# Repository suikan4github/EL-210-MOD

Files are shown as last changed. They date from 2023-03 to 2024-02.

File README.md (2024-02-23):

# EL-210-MOD
Alternative circuit for SHARP EL-210/EL-215 calculator

# Description

This is a circuit/board design for the alternate PCB for the SHARP EL-210/215 calculators. SHARP EL-210 series are manufactured around early 1980th. 
By using this alternate PCB, you can program any program as firmware of this
classic VFD calculator. 

There is an dedicated RPN firmware is located in the [rpn2026](https://github.com/suikan4github/rpn2026) project.

To make your own RPN calculator,
user must follow the procedure : 
1. Take the main board of the EL-210 out. 
1. Move the VFD from the old board to this board. 
1. Set this board into the EL-210 calculator. 
1. Program the board with the appropriate RPN firmware. 

# Circuit Design

You can found additional design resources : 
- [Schematic diagram](doc/EL-210-MOD.pdf).
- [Parts list](doc/partslist.csv).

## VFD specification
The VFD is 9-ST-20, manufactured by Futaba. The specification is not disclosed. 
Pin assignment has been investigated by [LI2026ODP](https://github.com/suikan4github/LI2026ODP/wiki/LI2026A) project.
- Anode voltage : 25V
- Heater voltage : 2.5v (Differential square wave drive), 21mA. 
- Grid cutoff : 4V

## Heater driver
The heater must be driven by differential alternate current. This is required to make the flat brightness between right-end and left-end of the VFD. If you drive 
the heater by DC, the voltage slope of the heater will make the slop of the brightness.

The analog switch provide the low voltage drop out current switching. The timing
is made by MCU timer.

## Grid bias 
The grid bias is required 4. Because the balanced drive of the heater makes
1.65V grid bias, we need only 2.5V more. 

## Key matrix
The key matrix has been investigated by also [LI2026ODP](https://github.com/suikan4github/LI2026ODP/wiki/KeyMatrix) project. 

The EL-21x series key matrix doesn't have any protection diode. Thus, to prevent the signal shortage,
the GPIO pins for the key matrix have to be configured : 
- Row : Open Drain output.
- Col : Input with pull-up register. 

To check the button pushed, output the "L" from the Row.
If the Column get "L", the button is pushed. 

|  Row  | Column 0  |  Column 1  |  Column 2  |
| :---: | :---: | :---: | :---: |
| 0 | CE |  X->M | 0 |
| 1 | | 7 | 4 |
| 2 | CM | 8 | 1 |
| 3 | . | 5 | % |
| 4 | + | RM | 2 |
| 5 | C | 9 | = |
| 6 | / | M- | |
| 7 | * | 6 | 3 |
| 8 | - | M+ |  sqrt |

## 24V
To supply the 24V to VFD, set EN24 signal to "H".

# Caution
In the case you order the PCB to a board manufacturer, you must specify the 
PCB thinness as 1.0mm. The standard 1.3mm is too thick. 

# Known Problems
The Grid bias is not deep as expected. It is -0.9V while expected -2.5v. 
It is left untouched because it is not problematic. 

# Gallery
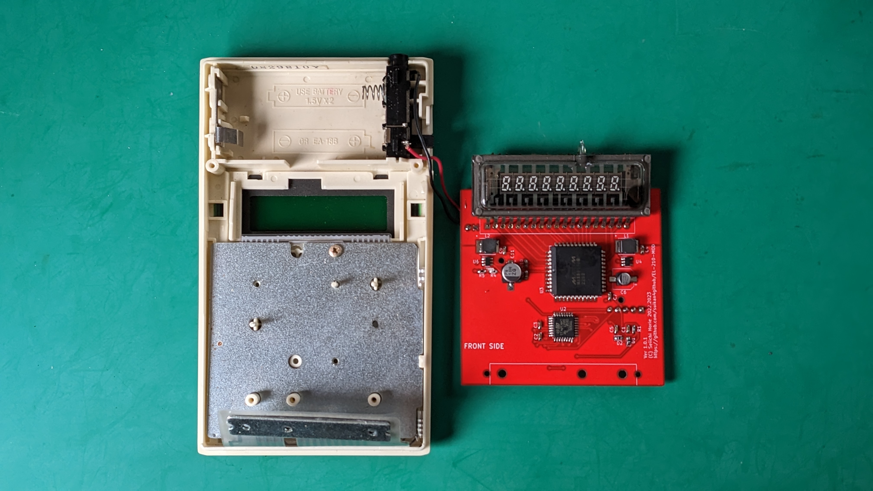
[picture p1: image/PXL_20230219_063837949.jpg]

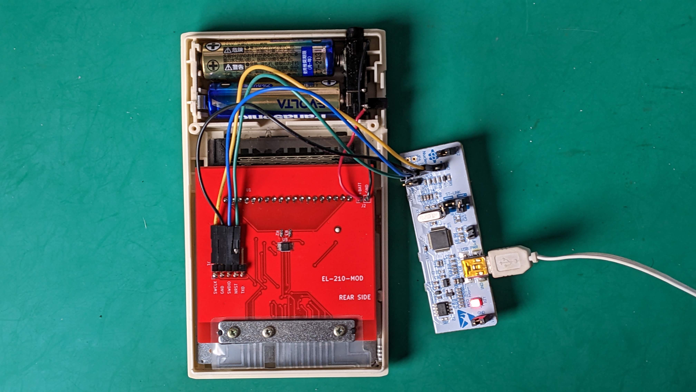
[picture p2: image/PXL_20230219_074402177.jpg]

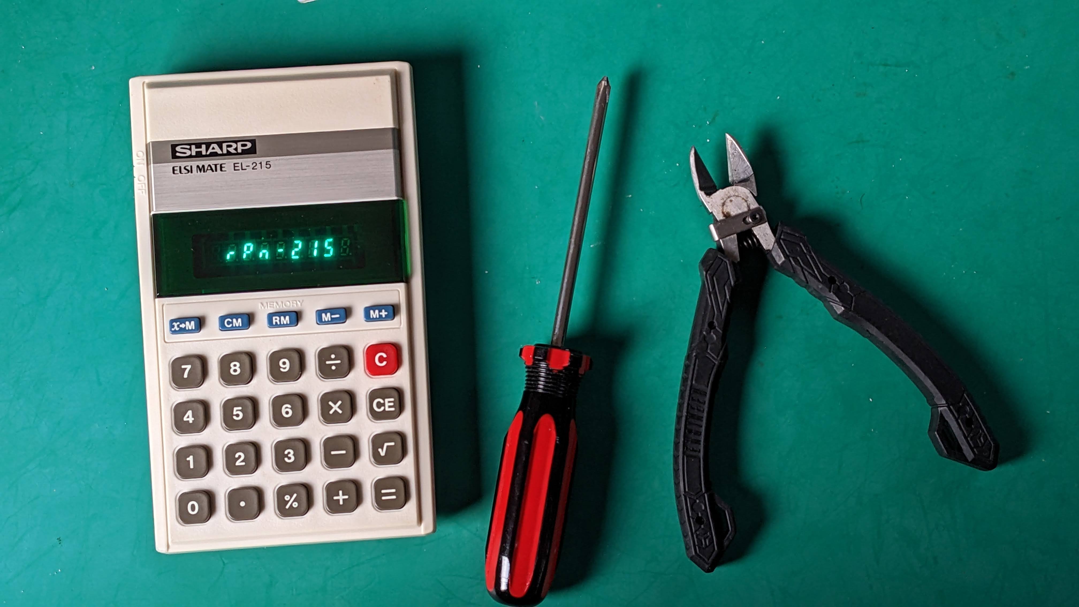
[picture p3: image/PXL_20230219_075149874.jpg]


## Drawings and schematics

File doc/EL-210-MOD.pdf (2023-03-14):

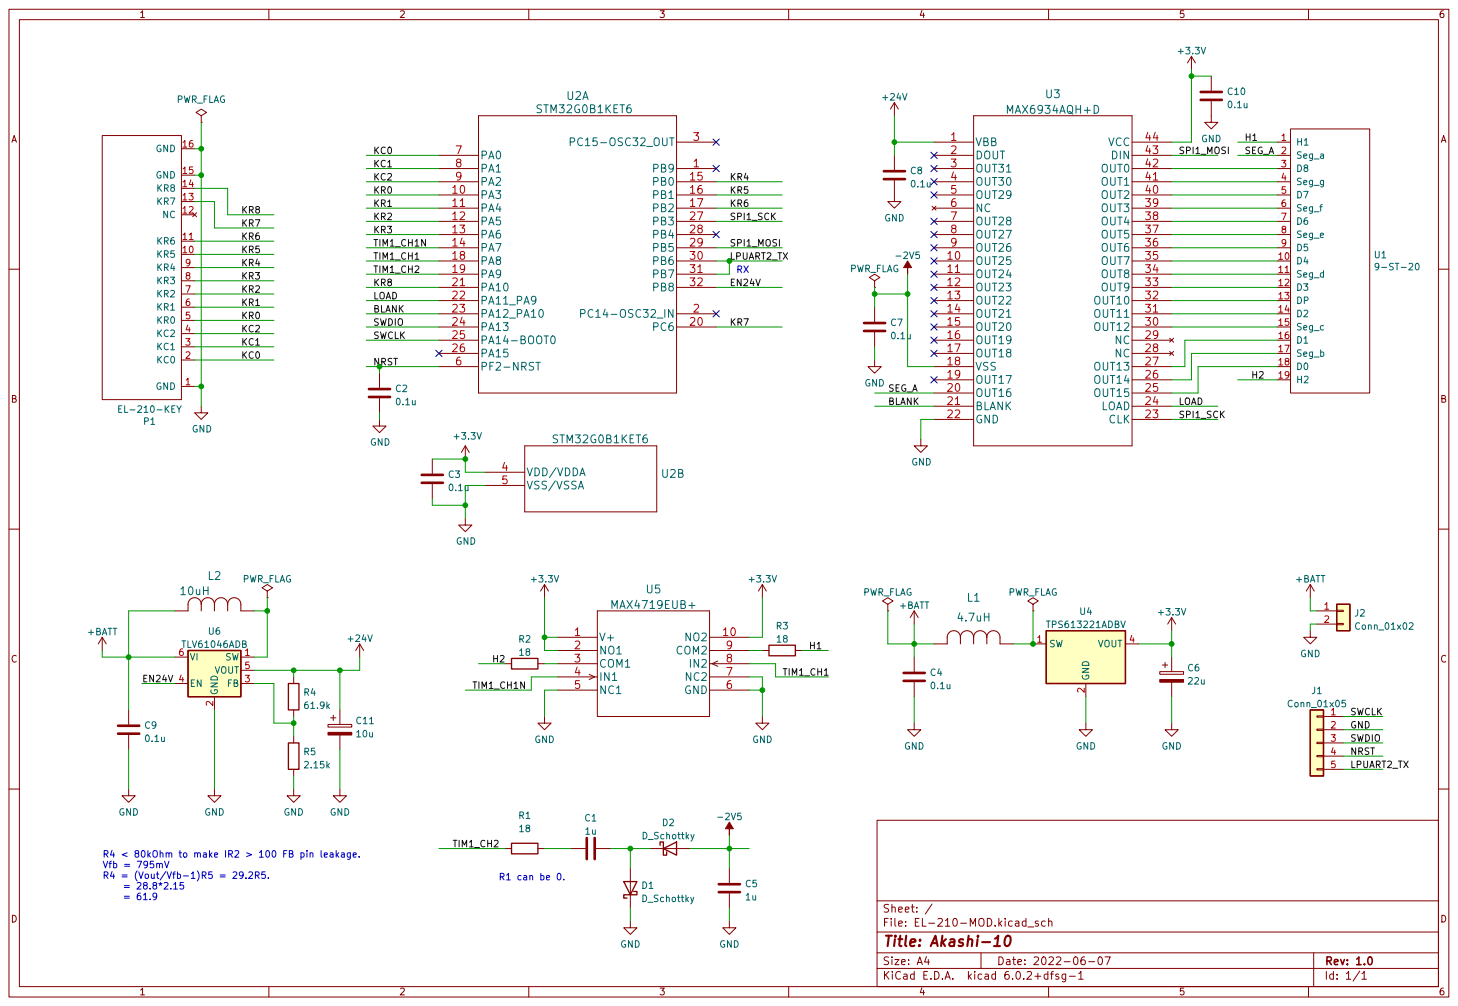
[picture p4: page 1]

2 FB 3 EN 4 VOUT 5 VI 6 U6 TLV61046ADB C9

File: EL-210-MOD.kicad_sch Sheet: /
Id: 1/1 Title: Akashi-10

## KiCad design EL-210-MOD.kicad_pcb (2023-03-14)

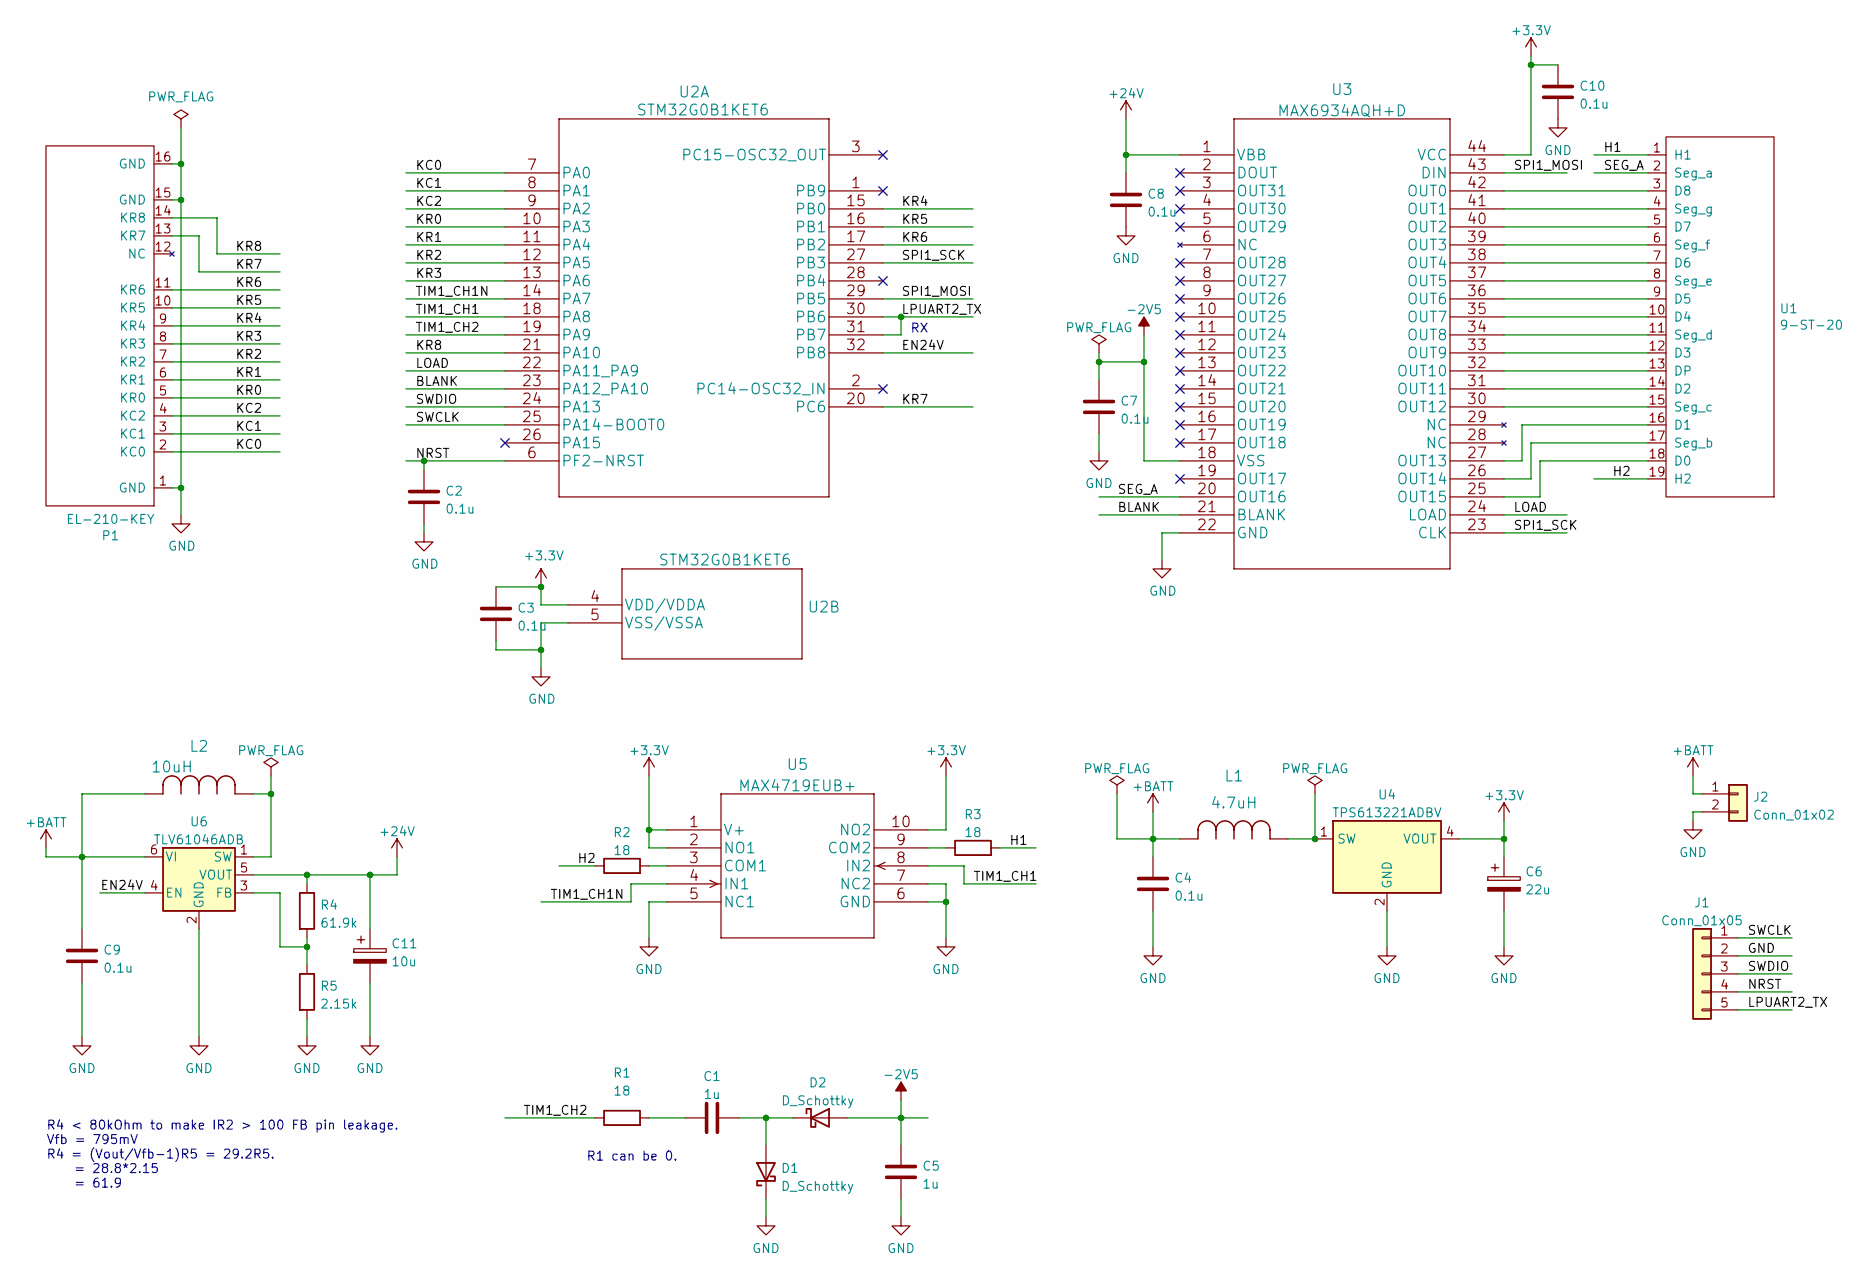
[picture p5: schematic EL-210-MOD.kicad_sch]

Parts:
C1, C5: 1u; C_0603_1608Metric_Pad1.08x0.95mm_HandSolder
C2, C3, C4, C7, C8, C9, C10: 0.1u; C_0603_1608Metric_Pad1.08x0.95mm_HandSolder
C6: 22u; CP_Elec_4x3.9
C11: 10u; CP_Elec_6.3x3.9
D1, D2: D_Schottky; D_0603_1608Metric_Pad1.05x0.95mm_HandSolder
J1: Conn_01x05; PinHeader_1x05_P2.54mm_Horizontal
J2: Conn_01x02; PinHeader_1x02_P2.54mm_Vertical
L1: 4.7uH; LQH5BPN100M38L
L2: 10uH; LQH5BPN100M38L
P1: EL-210-KEY
R1, R2, R3: 18; R_0603_1608Metric_Pad0.98x0.95mm_HandSolder
R4: 61.9k; R_0603_1608Metric_Pad0.98x0.95mm_HandSolder
R5: 2.15k; R_0603_1608Metric_Pad0.98x0.95mm_HandSolder
U1: 9-ST-20
U2: STM32G0B1KET6; LQFP-32_7x7mm_P0.8mm
U3: MAX6934AQH+D; PLCC44_handsoldering
U4: TPS613221ADBV; SOT-23-5
U5: MAX4719EUB+; MSOP-10_3x3mm_P0.5mm
U6: TLV61046ADB; SOT-23-6

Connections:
+3V3: C3.2, C6.1, C10.1, U2.4 (VDD/VDDA), U3.44 (VCC), U4.4 (VOUT), U5.1 (V+), U5.2 (NO1), U5.10 (NO2)
+24V: C8.1, C11.1, R4.1, U3.1 (VBB), U6.5 (VOUT)
+BATT: C4.1, C9.1, J2.1, L1.2, L2.2, U6.6 (VI)
-2V5: C5.1, C7.1, D2.2 (A), U3.18 (VSS)
/BLANK: U2.23 (PA12_PA10), U3.21 (BLANK)
/EN24V: U2.32 (PB8), U6.4 (EN)
/H1: R3.2, U1.1 (H1)
/H2: R2.1, U1.19 (H2)
/KC0: P1.2 (KC0), U2.7 (PA0)
/KC1: P1.3 (KC1), U2.8 (PA1)
/KC2: P1.4 (KC2), U2.9 (PA2)
/KR0: P1.5 (KR0), U2.10 (PA3)
/KR1: P1.6 (KR1), U2.11 (PA4)
/KR2: P1.7 (KR2), U2.12 (PA5)
/KR3: P1.8 (KR3), U2.13 (PA6)
/KR4: P1.9 (KR4), U2.15 (PB0)
/KR5: P1.10 (KR5), U2.16 (PB1)
/KR6: P1.11 (KR6), U2.17 (PB2)
/KR7: P1.13 (KR7), U2.20 (PC6)
/KR8: P1.14 (KR8), U2.21 (PA10)
/LOAD: U2.22 (PA11_PA9), U3.24 (LOAD)
/LPUART2_TX: J1.5, U2.30 (PB6), U2.31 (PB7)
/NRST: C2.1, J1.4, U2.6 (PF2-NRST)
/SEG_A: U1.2 (Seg_a), U3.20 (OUT16)
/SPI1_MOSI: U2.29 (PB5), U3.43 (DIN)
/SPI1_SCK: U2.27 (PB3), U3.23 (CLK)
/SWCLK: J1.1, U2.25 (PA14-BOOT0)
/SWDIO: J1.3, U2.24 (PA13)
/TIM1_CH1: U2.18 (PA8), U5.8 (IN2)
/TIM1_CH1N: U2.14 (PA7), U5.4 (IN1)
/TIM1_CH2: R1.1, U2.19 (PA9)
GND: C2.2, C3.1, C4.2, C5.2, C6.2, C7.2, C8.2, C9.2, C10.2, C11.2, D1.1 (K), J1.2, J2.2, P1.1 (GND), P1.15 (GND), P1.16 (GND), R5.2, U2.5 (VSS/VSSA), U3.22 (GND), U4.2 (GND), U5.5 (NC1), U5.6 (GND), U5.7 (NC2), U6.2 (GND)
unnamed: C1.1, R1.2
unnamed: C1.2, D1.2 (A), D2.1 (K)
unnamed: L1.1, U4.1 (SW)
unnamed: L2.1, U6.1 (SW)
unnamed: R2.2, U5.3 (COM1)
unnamed: R3.1, U5.9 (COM2)
unnamed: R4.2, R5.1, U6.3 (FB)
unnamed: U1.3 (D8), U3.42 (OUT0)
unnamed: U1.4 (Seg_g), U3.41 (OUT1)
unnamed: U1.5 (D7), U3.40 (OUT2)
unnamed: U1.6 (Seg_f), U3.39 (OUT3)
unnamed: U1.7 (D6), U3.38 (OUT4)
unnamed: U1.8 (Seg_e), U3.37 (OUT5)
unnamed: U1.9 (D5), U3.36 (OUT6)
unnamed: U1.10 (D4), U3.35 (OUT7)
unnamed: U1.11 (Seg_d), U3.34 (OUT8)
unnamed: U1.12 (D3), U3.33 (OUT9)
unnamed: U1.13 (DP), U3.32 (OUT10)
unnamed: U1.14 (D2), U3.31 (OUT11)
unnamed: U1.15 (Seg_c), U3.30 (OUT12)
unnamed: U1.16 (D1), U3.27 (OUT13)
unnamed: U1.17 (Seg_b), U3.26 (OUT14)
unnamed: U1.18 (D0), U3.25 (OUT15)

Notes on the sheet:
R4 < 80kOhm to make IR2 > 100 FB pin leakage. Vfb = 795mV R4 = (Vout/Vfb-1)R5 = 29.2R5. = 28.8*2.15 = 61.9
R1 can be 0.

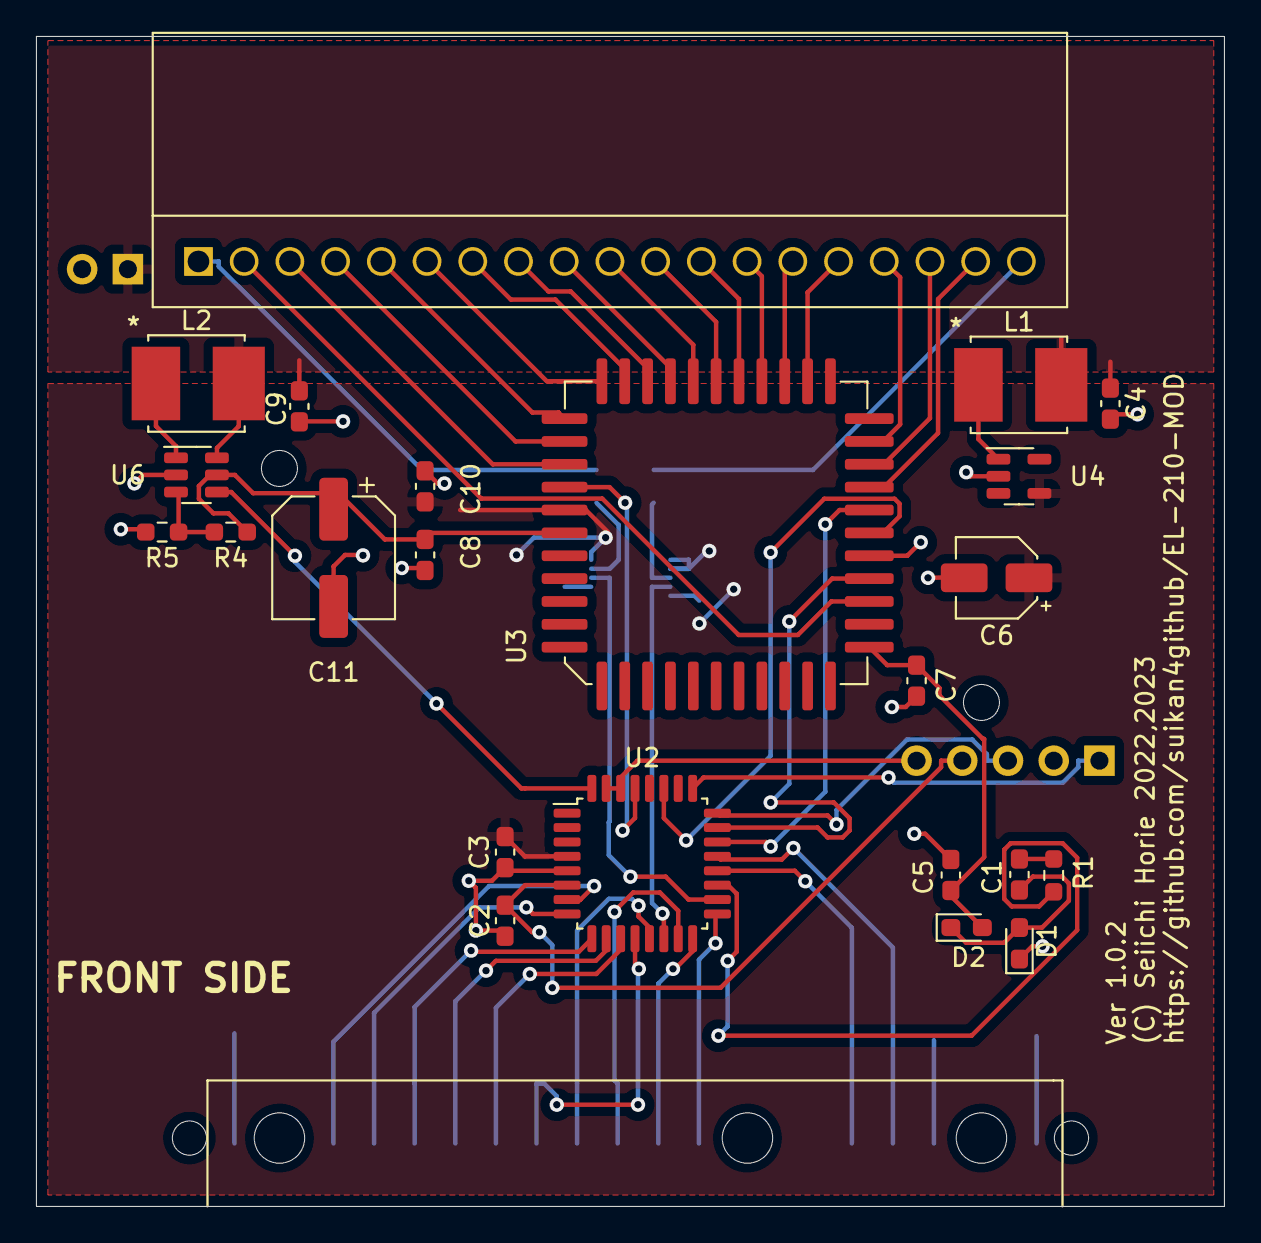
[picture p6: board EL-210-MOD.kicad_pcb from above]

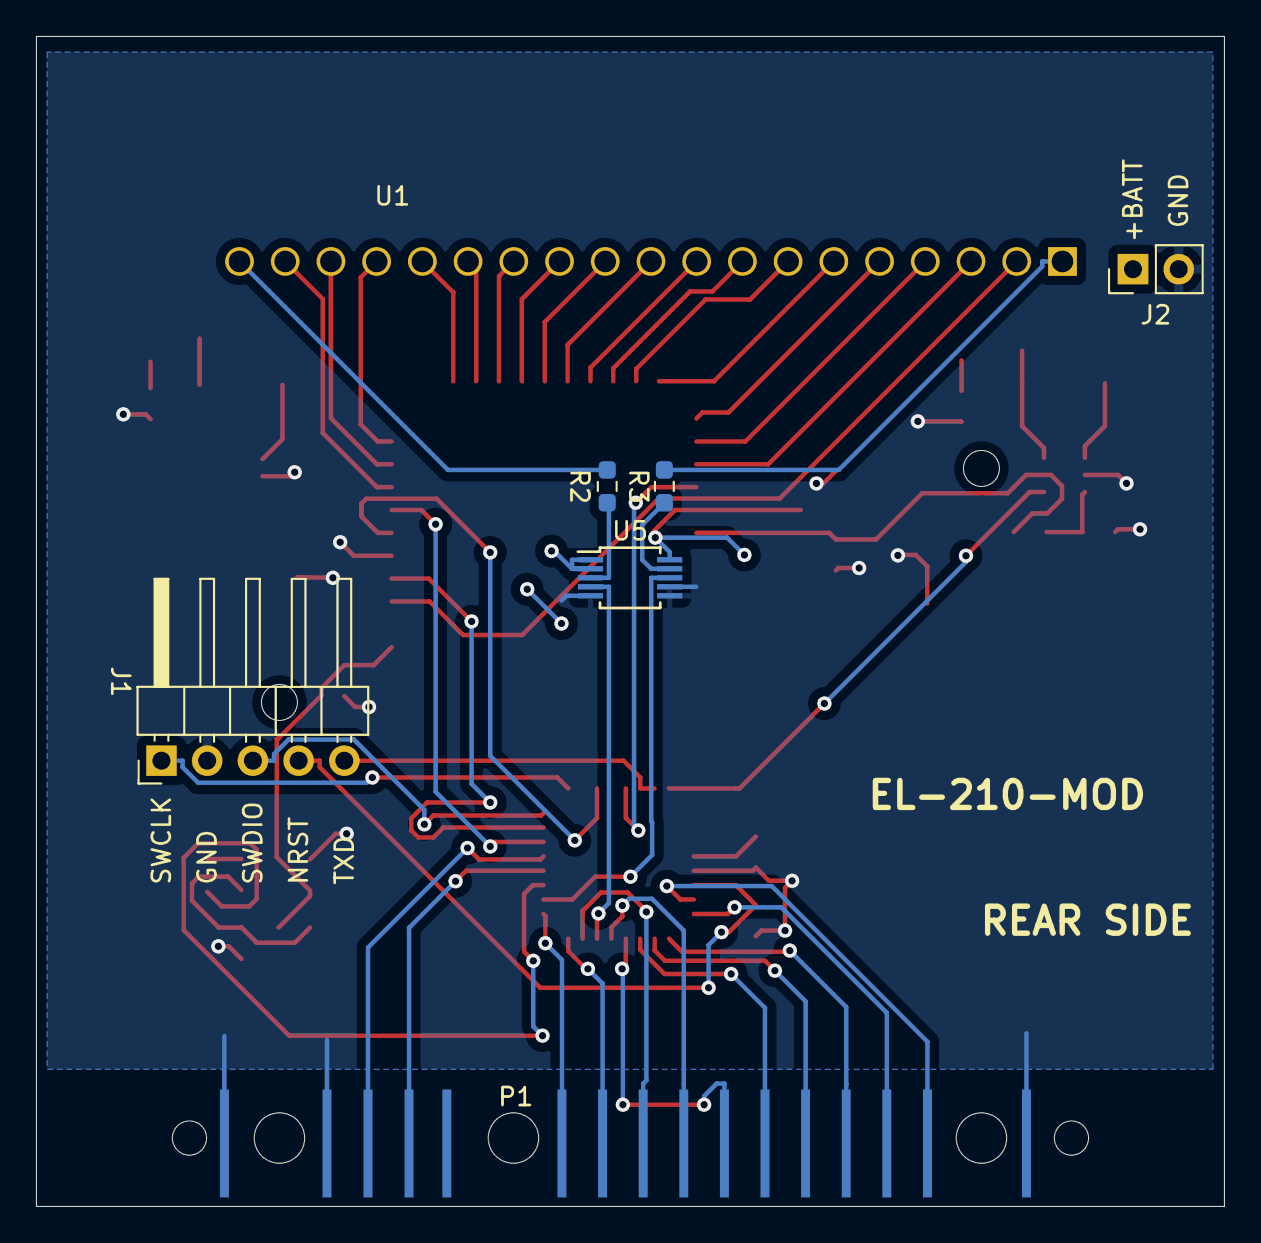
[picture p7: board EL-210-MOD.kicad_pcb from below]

Board: 2 copper layers, 66.0 x 65.0 mm, 36 parts (5 on the bottom side), 55 nets.

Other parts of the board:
H1, H2: hole_2.0mm
H3, H7: hole_1.9mm; hole_1.8mm
H4, H5, H6: hole_2.8mm

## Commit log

2022-11-12 Board layout copied from Akashi-10
    [EL-210-MOD.kicad_pcb, EL-210-MOD.kicad_sch, EL-210-MOD.sch]
2022-11-13 Add project symbol and footprint
2022-11-15 Rough layout of the digital part.
    [EL-210-MOD.kicad_pcb, EL-210-MOD.kicad_sch, EL-210-MOD.sch]
2022-11-15 Add analog parts.
    Waiting for SWD port.
    [EL-210-MOD.kicad_sch]
2022-11-21 Schematics is finished.
    [EL-210-MOD.kicad_pcb, EL-210-MOD.kicad_sch]
2022-11-21 Change PLCC footprint to handsolder type
    [EL-210-MOD.kicad_pcb, EL-210-MOD.kicad_sch]
2022-11-23 parts placed.
    The version number is written.
    The SMD pad of the Ls are modifed.
    Routing is not finished.
    [EL-210-MOD.kicad_pcb, EL-210-MOD.kicad_sch]
2022-11-23 Schematics layout refined.
    Added note on the Tc and R4/R5 expression.
    [EL-210-MOD.kicad_sch]
2022-11-23 Layout refined.
    Higher parts are moved to the front side to avoid the
    touch with the back cabinet.
    [EL-210-MOD.kicad_pcb, EL-210-MOD.kicad_sch]
2022-11-27 Layout finished.
    DRC passed except silkscreen minor problem.
    [EL-210-MOD.kicad_pcb, EL-210-MOD.kicad_sch]
2022-12-11 Gerber file generated
    [EL-210-MOD-B_Cu.gbl, EL-210-MOD-B_Mask.gbs, EL-210-MOD-B_Silkscreen.gbo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]
2023-01-09 Corrected signal name from TIM2_CH1 to TIM1_CH2
    Fixed typo. Layout is not changed.
    [EL-210-MOD.kicad_pcb, EL-210-MOD.kicad_sch]
2023-01-11 Update schematics.
    - Change the key matrix signal name.
    -- Including the re-order of the Key row.
    - Change the value of the R1 from 330 to 18.
    - Schematic is generatd in PDF.
    - Layout is generated in gerber.
    [EL-210-MOD-B_Cu.gbl, EL-210-MOD-B_Mask.gbs, EL-210-MOD-B_Silkscreen.gbo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]
2023-01-23 Refresh the layout.
    Regenerated the gerber for v1.0.1
    [EL-210-MOD-B_Cu.gbl, EL-210-MOD-B_Mask.gbs, EL-210-MOD-B_Silkscreen.gbo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]
2023-01-23 Update .gitignore
    gerber file is excluded.
2023-02-12 Fixed foot print of the C6 and C11.
    The foot prints of those capacitor was wrong.
    Corrected them.
    [EL-210-MOD-B_Cu.gbl, EL-210-MOD-B_Mask.gbs, EL-210-MOD-B_Silkscreen.gbo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]
2024-02-23 Fixed link to the schematics.

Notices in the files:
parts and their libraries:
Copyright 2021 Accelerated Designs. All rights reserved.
